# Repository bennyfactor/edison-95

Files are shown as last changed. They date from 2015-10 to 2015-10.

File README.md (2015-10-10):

HP 95LX Block for Intel Edison - Battery/Serial
=================================================

Based on the [SparkFun Block for Intel Edison - Battery/Power (DEV-13037)](https://www.sparkfun.com/products/13037)
and the reference design for the [MAX3218 low voltage TTL-RS232 transciever](https://datasheets.maximintegrated.com/en/ds/MAX3218.pdf)

This block or daughterboard, or whatever, is designed to fit in to the physical dimensions of the HP 95LX palmtop computer's
proto-PCMCIA slot. It has connections for two UARTs (the Edison's console out, and COM1?) that will allow either one to be connected to the HP95LX's serial header.
It also has the battery circuit for a lithium battery based on Sparkfun's design so that it can run on its own power while inside the palmtop!

Simply plug in a micro USB cable to charge.
The power switch removes the battery from the Edison while allowing it to charge via the microUSB cable.

Also fun LEDs for power status!

Repository Contents
-------------------
* **/hardware** - Eagle design files (.brd, .sch)

Documentation
--------------
* **[Hookup Guide](https://learn.sparkfun.com/tutorials/sparkfun-blocks-for-intel-edison---battery-block)** - Basic hookup guide for the SparkFun battery/power block.
* **[MAX3218 low voltage TTL-RS232 transciever](https://datasheets.maximintegrated.com/en/ds/MAX3218.pdf)** - Datasheet for the serial tranceiver.
* **[Intel Edison Hardware Guide](http://download.intel.com/support/edison/sb/edisonmodule_hg_331189004.pdf)** - Datasheet for the Edison module.

Sparkfun Product Versions
----------------
* [Battery Block](https://www.sparkfun.com/products/13037)- Battery block.
* [Power Block](https://www.sparkfun.com/products/13727)- Battery block without lipo battery installed.

License Information
-------------------

This product is _**open source**_!

Please review the LICENSE.md file for license information.

If you have any questions or concerns on licensing, please contact techsupport@sparkfun.com.

Distributed as-is; no warranty is given.

- Your friends at SparkFun. ALSO BENNY

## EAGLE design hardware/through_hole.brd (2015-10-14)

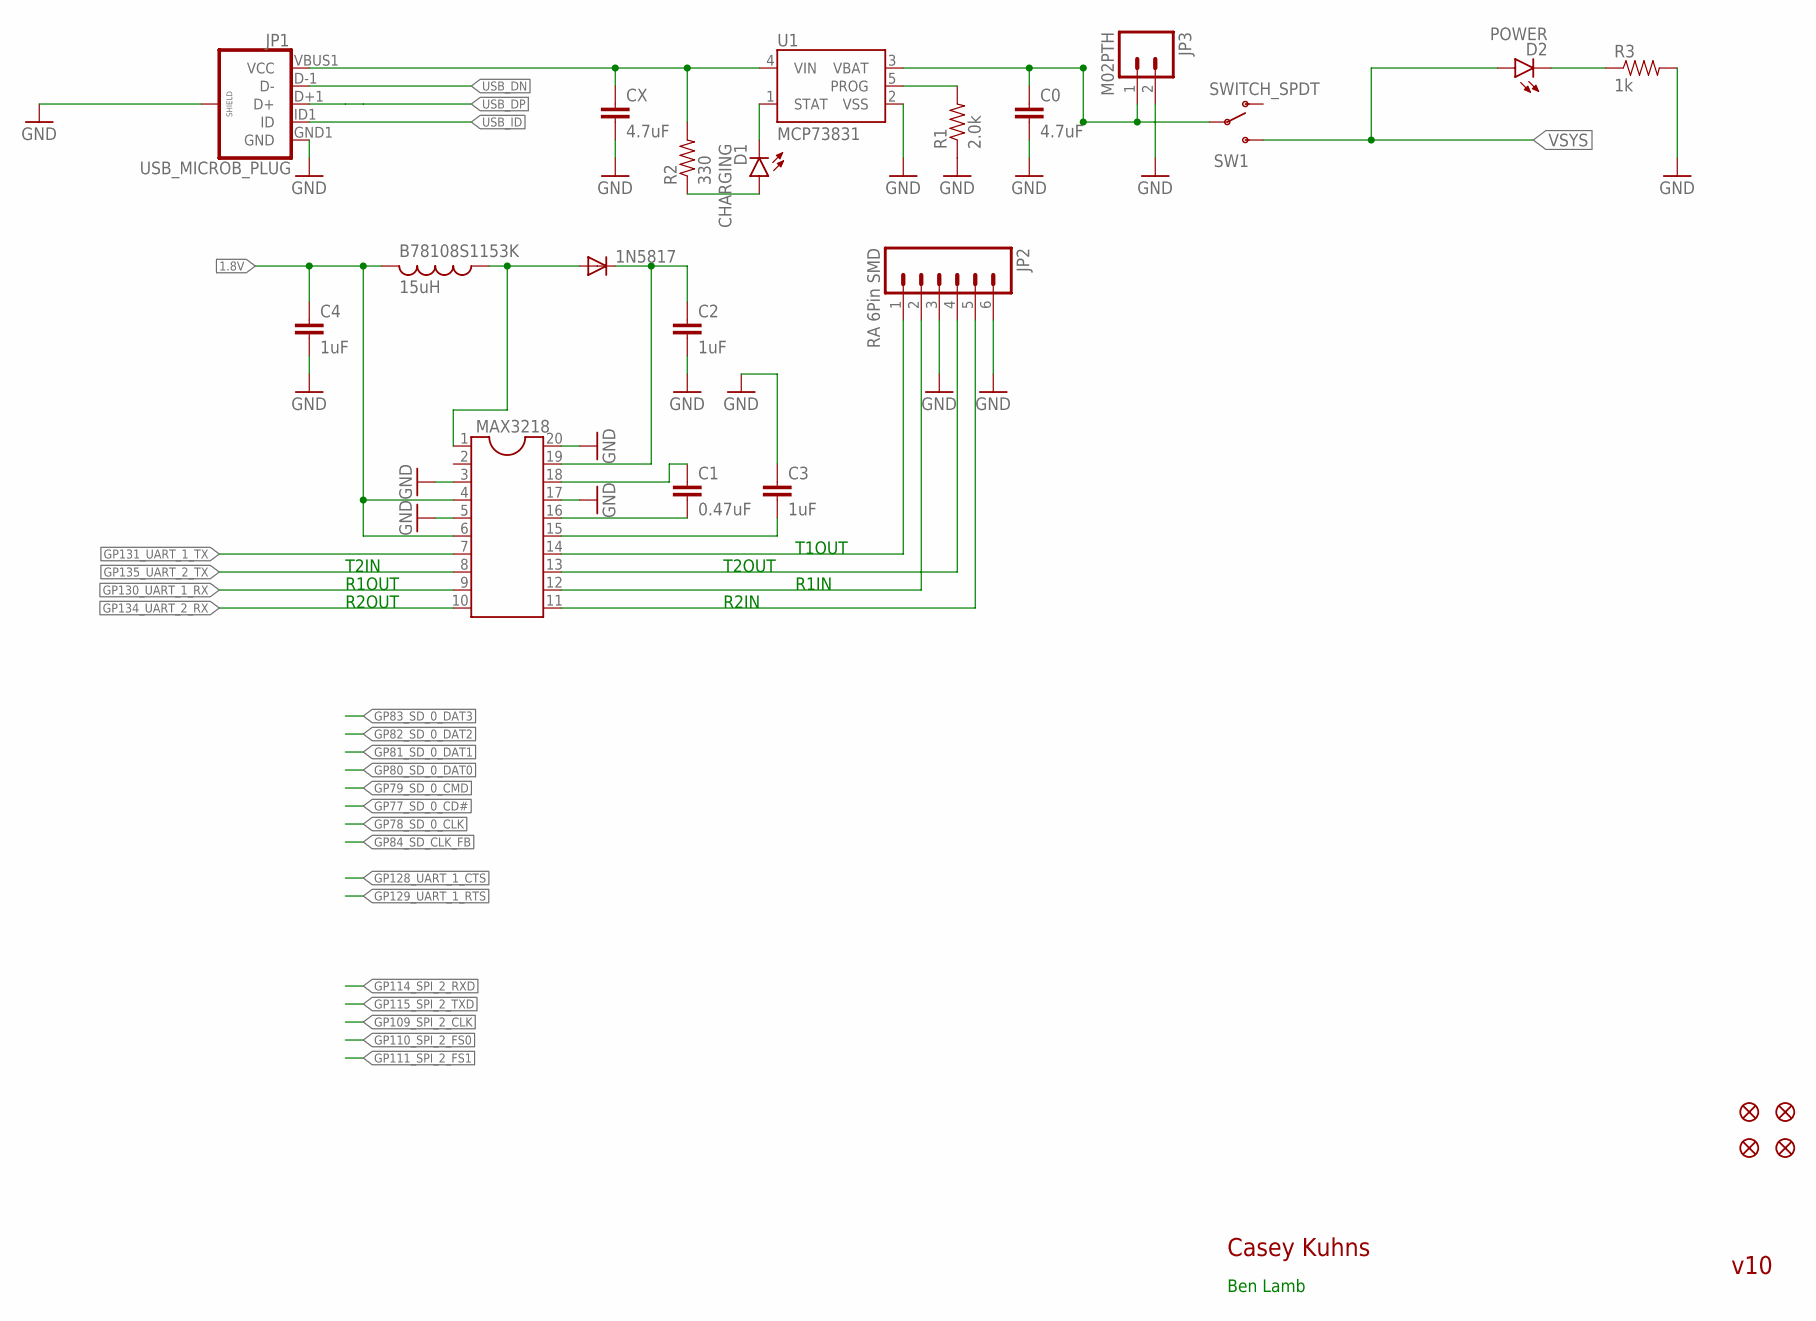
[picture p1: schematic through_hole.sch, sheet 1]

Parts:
1N5817: DIODE-DO41-10; DO41-10
B78108S1153K: 15uH; 0207/15
C0: 4.7uF; 0603-CAP
C1: 0.47uF; CAP-PTH-5MM
C2, C3, C4: 1uF; CAP-PTH-5MM
CX: 4.7uF; 0603-CAP
D1: CHARGING; LED-0603
D2: POWER; LED-0603
FID1, FID2, FID3, FID4: FIDUCIAL1X2; FIDUCIAL-1X2
JP1: USB_MICROB_PLUG; USB-B-MICRO-SMD_V03
JP2: RA 6Pin SMD; 1X06-SMD
JP3: M02PTH; 1X02
MAX3218: DIL20
R1: 2.0k; 0603-RES
R2: 330; 0603-RES
R3: 1k; 0603-RES
SW1: SWITCH_SPDT; KPS-1290
U1: MCP73831; SOT23-5

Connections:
1: 1N5817.A, B78108S1153K.1, MAX3218.1
1.8V: B78108S1153K.2, C4.1, MAX3218.4, MAX3218.6; also elsewhere on the board
CX: CX.1, JP1.VBUS1 (VCC), R2.2, U1.4 (VIN)
GND: C0.2, C2.2, C3.1, C4.2, CX.2, JP1.GND1 (GND), JP1.SHIELD1 (SHIELD), JP1.SHIELD2 (SHIELD), JP1.SHIELD3 (SHIELD), JP2.3, JP2.6, JP3.2, MAX3218.3, MAX3218.5, MAX3218.17, MAX3218.20, R1.1, R3.2, U1.2 (VSS); also elsewhere on the board
GP130_UART_1_RX: MAX3218.9; also elsewhere on the board
GP131_UART_1_TX: MAX3218.7; also elsewhere on the board
GP134_UART_2_RX: MAX3218.10; also elsewhere on the board
GP135_UART_2_TX: MAX3218.8; also elsewhere on the board
unnamed: D2.C, R3.1
unnamed: R1.2, U1.5 (PROG)
unnamed: D1.A, R2.1
unnamed: D1.C, U1.1 (STAT)
unnamed: C3.2, MAX3218.15
unnamed: C1.1, MAX3218.18
unnamed: C1.2, MAX3218.16
unnamed: JP2.4, MAX3218.13
unnamed: JP2.2, MAX3218.12
unnamed: JP2.5, MAX3218.11
unnamed: 1N5817.C, C2.1, MAX3218.19
T1OUT: JP2.1, MAX3218.14
USB_DN: JP1.D-1 (D-); also elsewhere on the board
USB_DP: JP1.D+1 (D+); also elsewhere on the board
USB_ID: JP1.ID1 (ID); also elsewhere on the board
VBAT: C0.1, JP3.1, SW1.P, U1.3 (VBAT)
VSYS: D2.A, SW1.S; also elsewhere on the board

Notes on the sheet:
Casey Kuhns
v10
R2IN
R1IN
T2OUT
T1OUT
T2IN
R1OUT
R2OUT
Ben Lamb

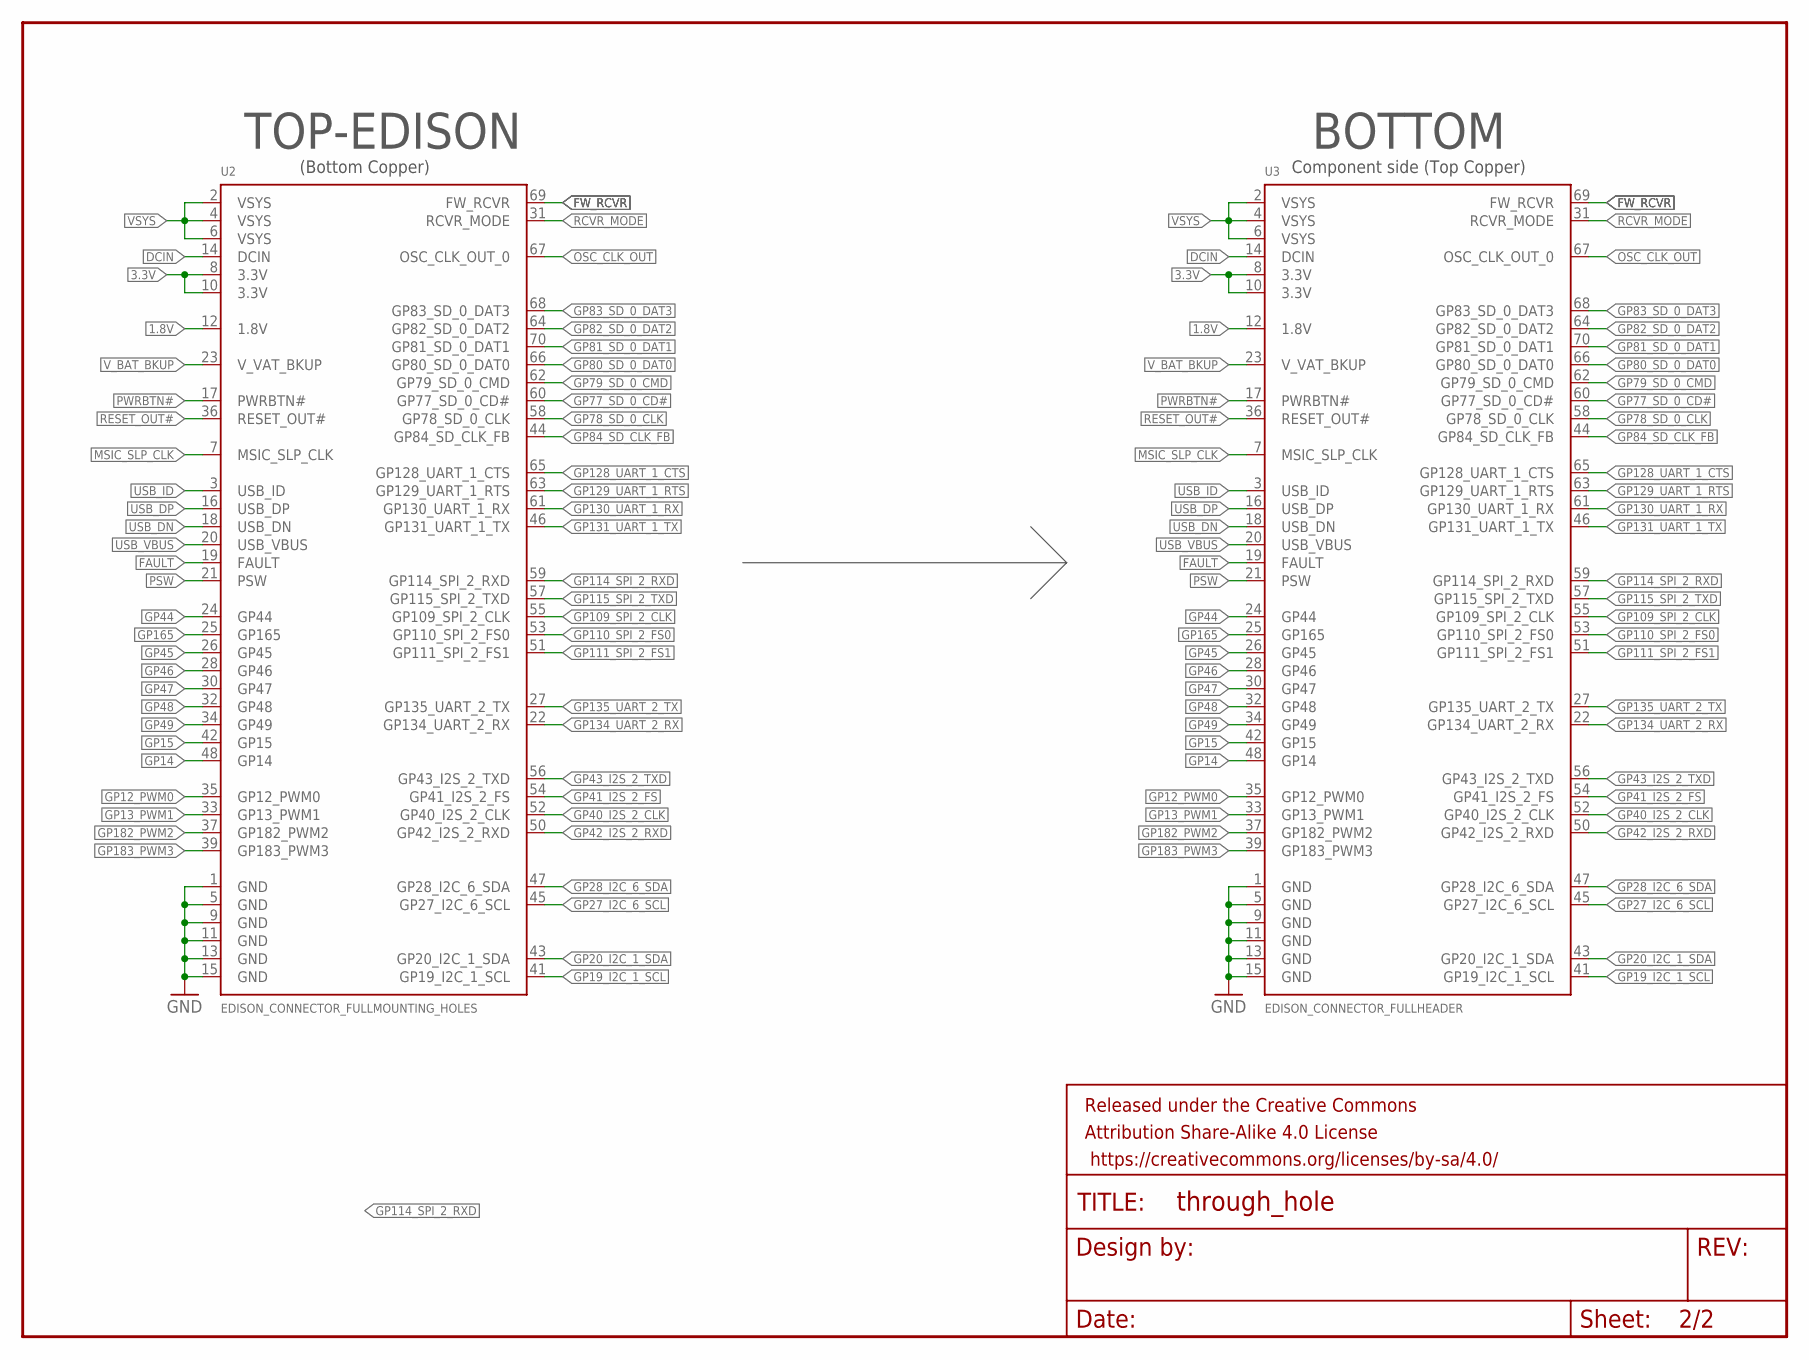
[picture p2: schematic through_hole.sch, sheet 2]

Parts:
FRAME2: FRAME-LETTER; CREATIVE_COMMONS
U2: EDISON_CONNECTOR_FULLMOUNTING_HOLES; EDISON_DAUGHTER
U3: EDISON_CONNECTOR_FULLHEADER; DF40C-70DP-0.4(51)

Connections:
1.8V: U2.12 (1.8V), U3.12 (1.8V); also elsewhere on the board
3.3V: U2.8 (3.3V), U2.10 (3.3V), U3.8 (3.3V), U3.10 (3.3V)
DCIN: U2.14 (DCIN), U3.14 (DCIN)
FAULT: U2.19 (FAULT), U3.19 (FAULT)
FW_RCVR: U2.69 (FW_RCVR), U3.69 (FW_RCVR)
GND: U2.1 (GND), U2.5 (GND), U2.9 (GND), U2.11 (GND), U2.13 (GND), U2.15 (GND), U3.1 (GND), U3.5 (GND), U3.9 (GND), U3.11 (GND), U3.13 (GND), U3.15 (GND); also elsewhere on the board
GP12_PWM0: U2.35 (GP12_PWM0), U3.35 (GP12_PWM0)
GP13_PWM1: U2.33 (GP13_PWM1), U3.33 (GP13_PWM1)
GP14: U2.48 (GP14), U3.48 (GP14)
GP15: U2.42 (GP15), U3.42 (GP15)
GP19_I2C_1_SCL: U2.41 (GP19_I2C_1_SCL), U3.41 (GP19_I2C_1_SCL)
GP20_I2C_1_SDA: U2.43 (GP20_I2C_1_SDA), U3.43 (GP20_I2C_1_SDA)
GP27_I2C_6_SCL: U2.45 (GP27_I2C_6_SCL), U3.45 (GP27_I2C_6_SCL)
GP28_I2C_6_SDA: U2.47 (GP28_I2C_6_SDA), U3.47 (GP28_I2C_6_SDA)
GP40_I2S_2_CLK: U2.52 (GP40_I2S_2_CLK), U3.52 (GP40_I2S_2_CLK)
GP41_I2S_2_FS: U2.54 (GP41_I2S_2_FS), U3.54 (GP41_I2S_2_FS)
GP42_I2S_2_RXD: U2.50 (GP42_I2S_2_RXD), U3.50 (GP42_I2S_2_RXD)
GP43_I2S_2_TXD: U2.56 (GP43_I2S_2_TXD), U3.56 (GP43_I2S_2_TXD)
GP44: U2.24 (GP44), U3.24 (GP44)
GP45: U2.26 (GP45), U3.26 (GP45)
GP46: U2.28 (GP46), U3.28 (GP46)
GP47: U2.30 (GP47), U3.30 (GP47)
GP48: U2.32 (GP48), U3.32 (GP48)
GP49: U2.34 (GP49), U3.34 (GP49)
GP77_SD_0_CD#: U2.60 (GP77_SD_0_CD#), U3.60 (GP77_SD_0_CD#)
GP78_SD_0_CLK: U2.58 (GP78_SD_0_CLK), U3.58 (GP78_SD_0_CLK)
GP79_SD_0_CMD: U2.62 (GP79_SD_0_CMD), U3.62 (GP79_SD_0_CMD)
GP80_SD_0_DAT0: U2.66 (GP80_SD_0_DAT0), U3.66 (GP80_SD_0_DAT0)
GP81_SD_0_DAT1: U2.70 (GP81_SD_0_DAT1), U3.70 (GP81_SD_0_DAT1)
GP82_SD_0_DAT2: U2.64 (GP82_SD_0_DAT2), U3.64 (GP82_SD_0_DAT2)
GP83_SD_0_DAT3: U2.68 (GP83_SD_0_DAT3), U3.68 (GP83_SD_0_DAT3)
GP84_SD_CLK_FB: U2.44 (GP84_SD_CLK_FB), U3.44 (GP84_SD_CLK_FB)
GP109_SPI_2_CLK: U2.55 (GP109_SPI_2_CLK), U3.55 (GP109_SPI_2_CLK)
GP110_SPI_2_FS0: U2.53 (GP110_SPI_2_FS0), U3.53 (GP110_SPI_2_FS0)
GP111_SPI_2_FS1: U2.51 (GP111_SPI_2_FS1), U3.51 (GP111_SPI_2_FS1)
GP114_SPI_2_RXD: U2.59 (GP114_SPI_2_RXD), U3.59 (GP114_SPI_2_RXD)
GP115_SPI_2_TXD: U2.57 (GP115_SPI_2_TXD), U3.57 (GP115_SPI_2_TXD)
GP128_UART_1_CTS: U2.65 (GP128_UART_1_CTS), U3.65 (GP128_UART_1_CTS)
GP129_UART_1_RTS: U2.63 (GP129_UART_1_RTS), U3.63 (GP129_UART_1_RTS)
GP130_UART_1_RX: U2.61 (GP130_UART_1_RX), U3.61 (GP130_UART_1_RX); also elsewhere on the board
GP131_UART_1_TX: U2.46 (GP131_UART_1_TX), U3.46 (GP131_UART_1_TX); also elsewhere on the board
GP134_UART_2_RX: U2.22 (GP134_UART_2_RX), U3.22 (GP134_UART_2_RX); also elsewhere on the board
GP135_UART_2_TX: U2.27 (GP135_UART_2_TX), U3.27 (GP135_UART_2_TX); also elsewhere on the board
GP165: U2.25 (GP165), U3.25 (GP165)
GP182_PWM2: U2.37 (GP182_PWM2), U3.37 (GP182_PWM2)
GP183_PWM3: U2.39 (GP183_PWM3), U3.39 (GP183_PWM3)
MSIC_SLP_CLK: U2.7 (MSIC_SLP_CLK), U3.7 (MSIC_SLP_CLK)
OSC_CLK_OUT: U2.67 (OSC_CLK_OUT_0), U3.67 (OSC_CLK_OUT_0)
PSW: U2.21 (PSW), U3.21 (PSW)
PWRBTN#: U2.17 (PWRBTN#), U3.17 (PWRBTN#)
RCVR_MODE: U2.31 (RCVR_MODE), U3.31 (RCVR_MODE)
RESET_OUT#: U2.36 (RESET_OUT#), U3.36 (RESET_OUT#)
USB_DN: U2.18 (USB_DN), U3.18 (USB_DN); also elsewhere on the board
USB_DP: U2.16 (USB_DP), U3.16 (USB_DP); also elsewhere on the board
USB_ID: U2.3 (USB_ID), U3.3 (USB_ID); also elsewhere on the board
USB_VBUS: U2.20 (USB_VBUS), U3.20 (USB_VBUS)
VSYS: U2.2 (VSYS), U2.4 (VSYS), U2.6 (VSYS), U3.2 (VSYS), U3.4 (VSYS), U3.6 (VSYS); also elsewhere on the board
V_BAT_BKUP: U2.23 (V_VAT_BKUP), U3.23 (V_VAT_BKUP)

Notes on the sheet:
TOP-EDISON
BOTTOM
Component side (Top Copper)
(Bottom Copper)

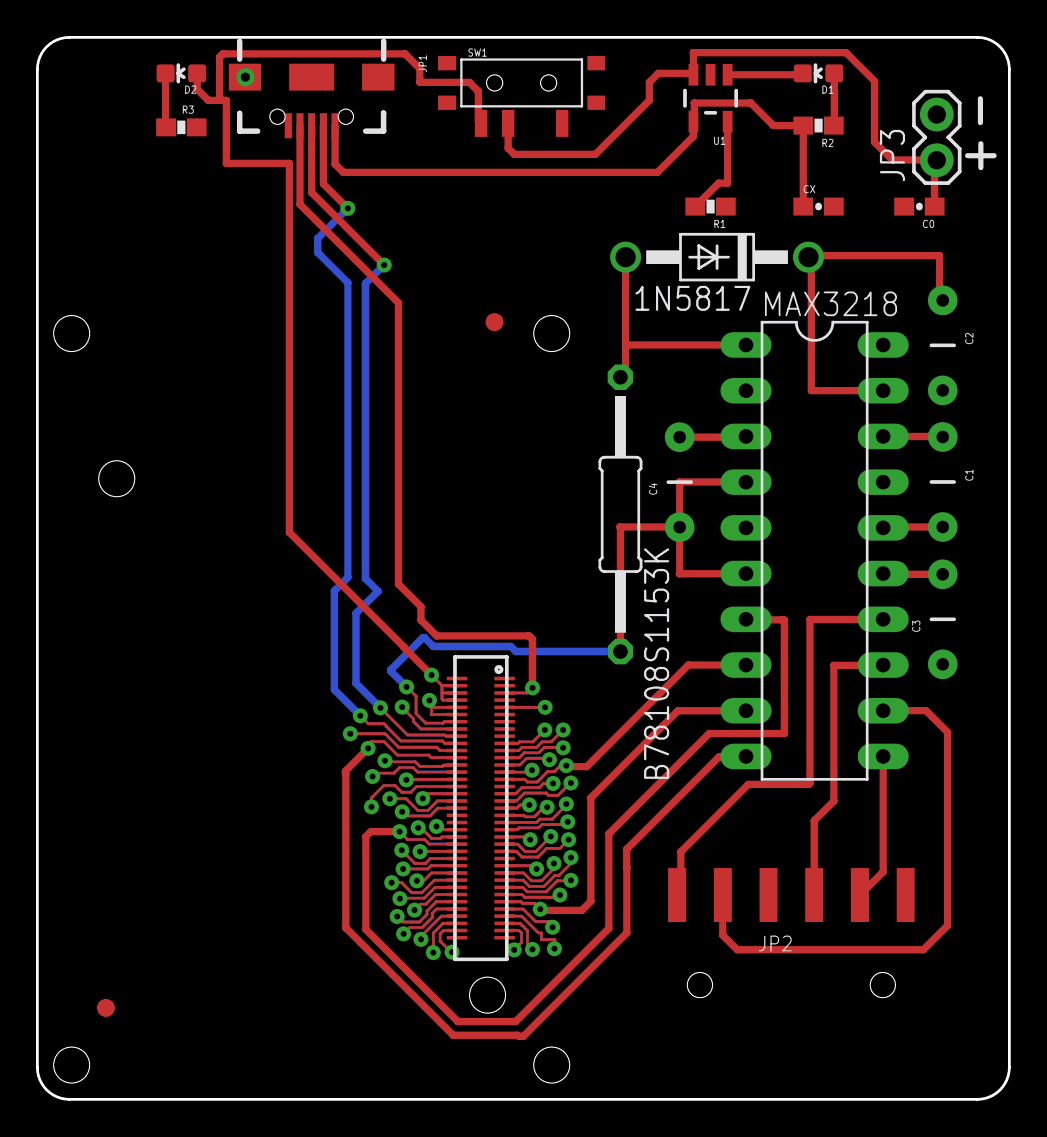
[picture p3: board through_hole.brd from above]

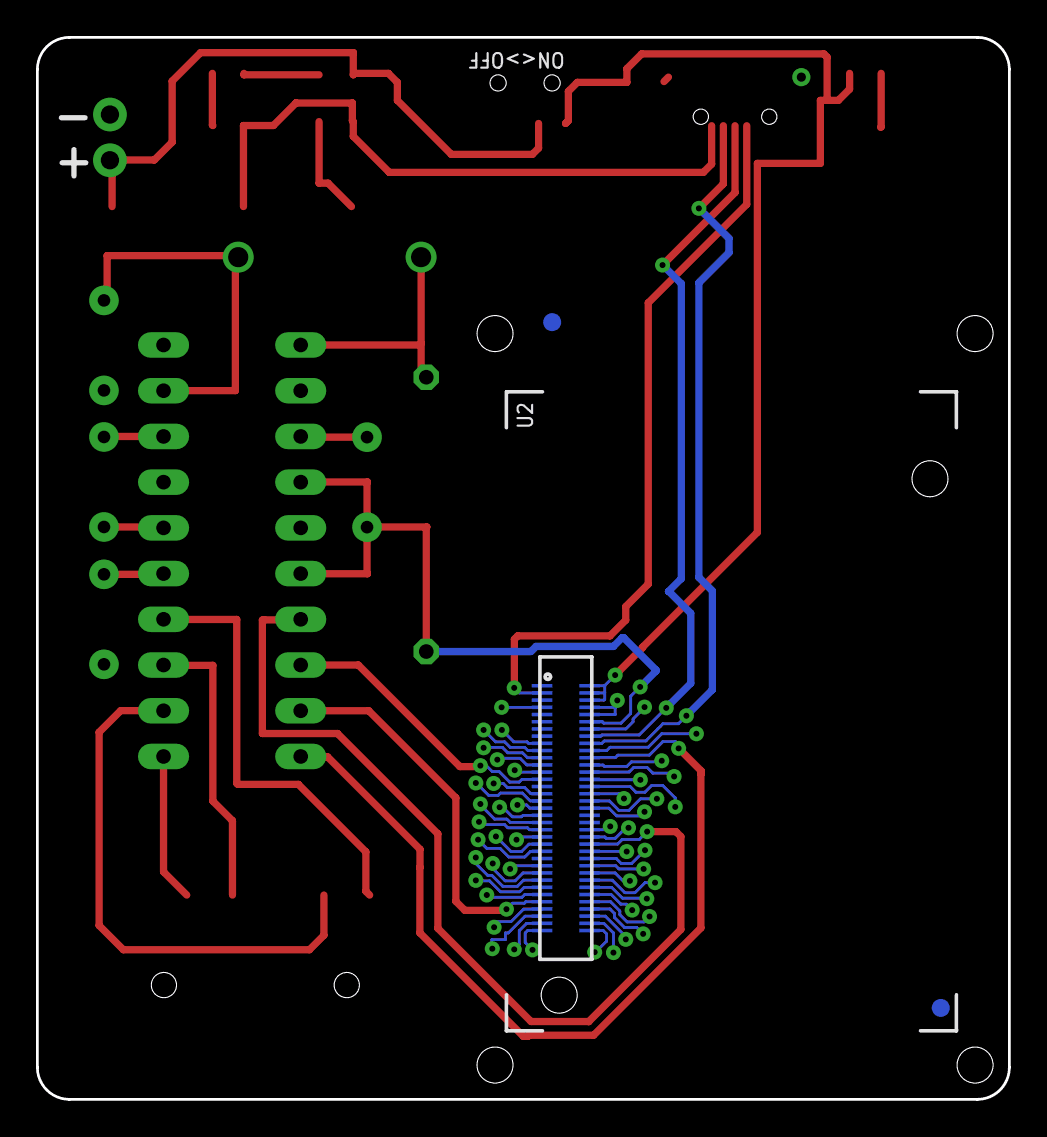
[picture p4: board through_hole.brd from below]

Board: 2 copper layers, 54.0 x 59.0 mm, 26 parts (4 on the bottom side), 73 nets.

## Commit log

2015-10-07 initial commit as board for HP95LX
    [Battery_Block-GiantPanel-v10.brd, Battery_Block-Panel-v10.brd, compact.brd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]
2015-10-07 Initial HP95LX daughterboard layouts
    [compact.brd, compact.sch]
2015-10-07 add USB data lines, use 1.8v line, not vcc, for Max3218, DRC fixes
    [compact.brd, compact.sch]
2015-10-10 Update readme, board routing fixes, change LED names to functions vice colors
    [compact.brd, compact.sch]
2015-10-14 add version with through hole transistors for ease of soldering
    [through_hole.brd, through_hole.sch]
2015-10-14 Add BOM for thru hole board

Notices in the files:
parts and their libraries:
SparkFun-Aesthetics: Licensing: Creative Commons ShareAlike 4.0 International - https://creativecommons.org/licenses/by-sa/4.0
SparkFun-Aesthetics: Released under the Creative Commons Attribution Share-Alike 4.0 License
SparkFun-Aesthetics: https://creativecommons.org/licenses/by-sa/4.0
